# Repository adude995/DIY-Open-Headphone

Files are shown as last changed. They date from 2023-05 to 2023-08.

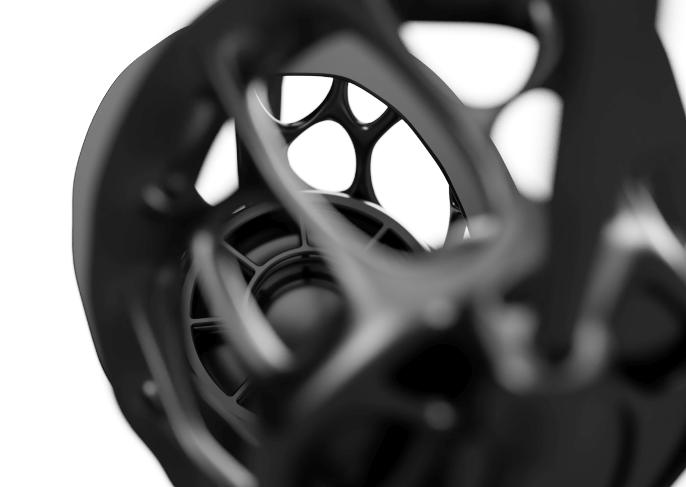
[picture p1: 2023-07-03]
photos/rendering_2.png

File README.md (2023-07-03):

# mushroom - DIY ultralight open headphones

## Overview

This project is about acoustically transparent DIY 3D-printable headphones. They are designed to be used in combination with signal processing, either with binaural convolution or just a simple eq.

The design is kept simple and only requires 5 (+2) printed parts in total. Their acoustically transparent design makes them not only nice open back headphones but also perfectly suited for AR applications. If bass reproduction is more important than transparency, felt pads, acting like additional masses, can be put in front of the driver.

This repository relates to the open-acces paper "Ultralight circumaural open headphone", which was presented at the Audio Engineering Society Convention in May 2023 in Espoo, Finland. Therein, development process and measurements are documented. It can be found at https://www.aes.org/e-lib/browse.cfm?elib=22075

Plans and instructions to build them on your own are found below or will be added soon.

## Background

The main question considered in this project was how a headphone design could look like, if the benefits of equalization were considered in the development process from the start. In addition, since the work was intended to be a freely accessible DIY project, 3D printing was chosen as the manufacturing method to ensure feasibility and repairability.

## Features

- 3D printable design
- Optimized for mixed and virtual reality
- Great for listening to music
- Convertable to different needs (hear-through vs low-end)

## Getting Started

To get started with building these headphones, follow these steps:

1. Clone or download this repository to your local machine.
2. Open the design files in your preferred 3D printing software.
3. Print the design using the recommended settings (to come, if not yet available)
4. Follow the assembly instructions provided in the repository to build the headphones together. (to come, if not yet available)

## License

This project is licensed under the Creative Commons Attribution-NonCommercial-NoDerivatives 4.0 International License. See the LICENSE file for more information.

## Contact

If you have any questions or feedback about this project, please contact me at alex.muelleder@gmx.at.

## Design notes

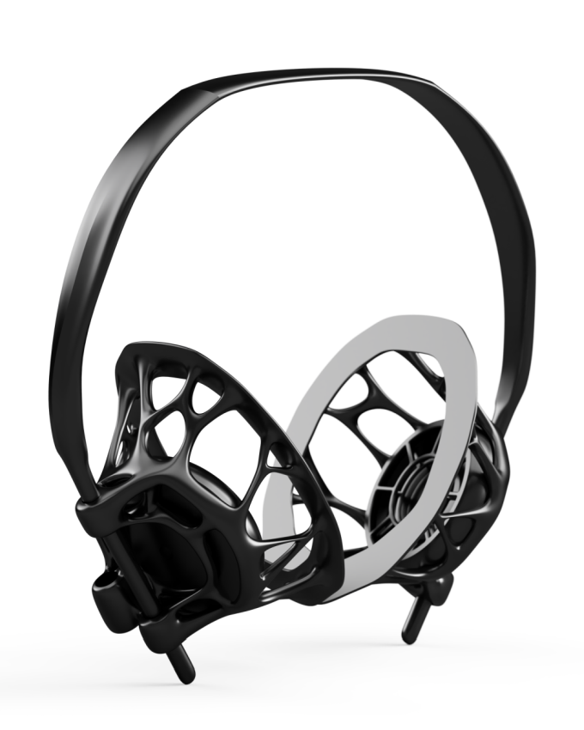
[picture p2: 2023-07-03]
photos/rendering_1.png

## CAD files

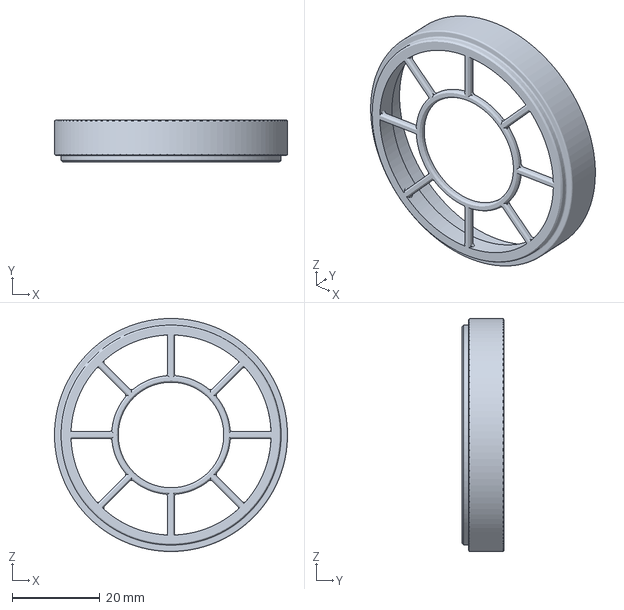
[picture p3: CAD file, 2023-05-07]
files/driver_insert_v0.1.3mf
53.0 x 9.50 x 53.0 mm

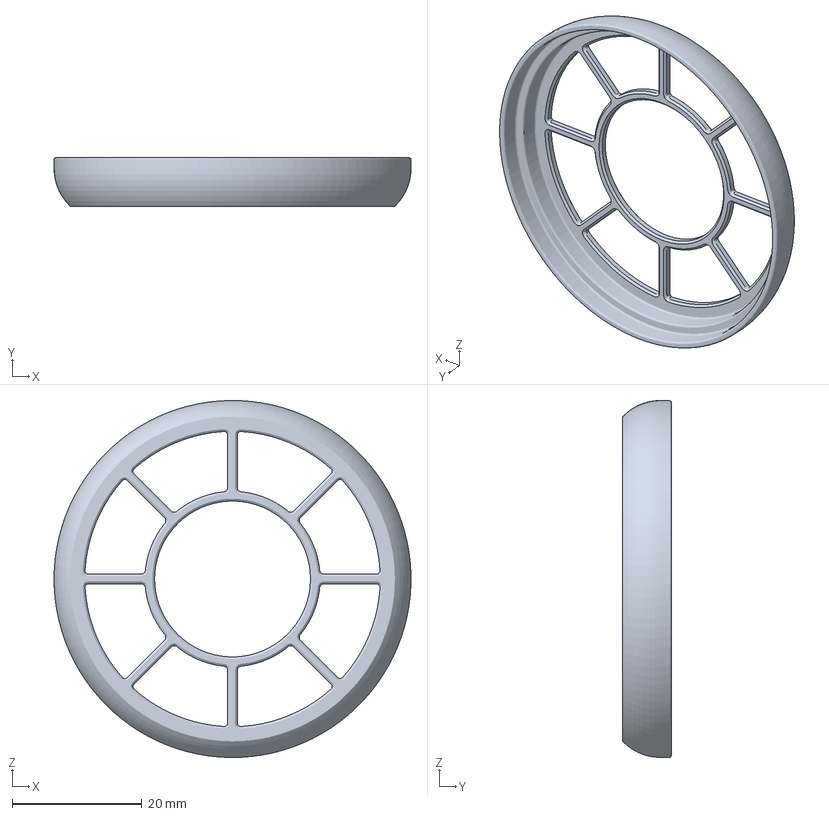
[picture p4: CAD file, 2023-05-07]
files/padholder_v0.1.3mf
55.0 x 7.50 x 55.0 mm

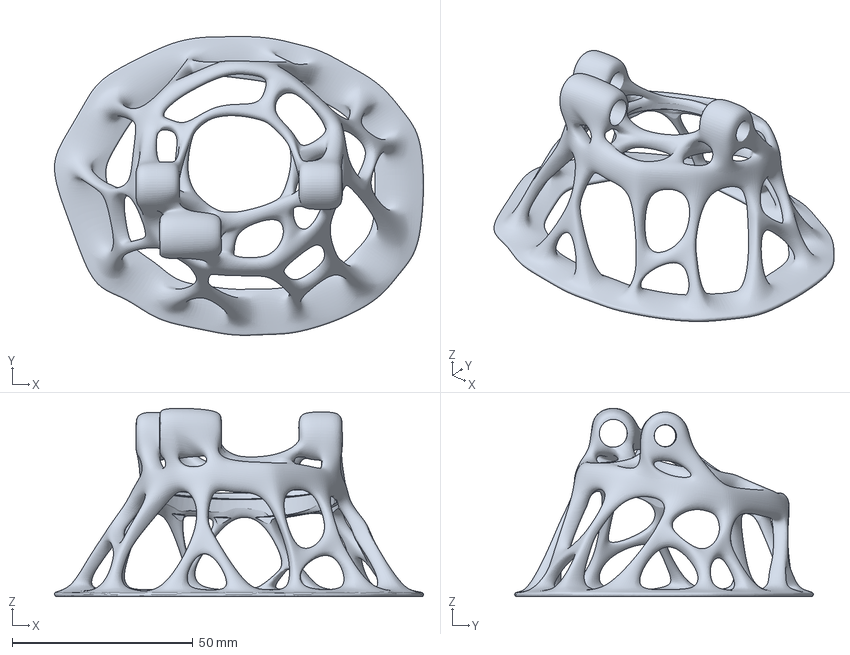
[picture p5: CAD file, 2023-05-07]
files/earcup_left_v0.1.3mf
102.0 x 82.6 x 52.1 mm

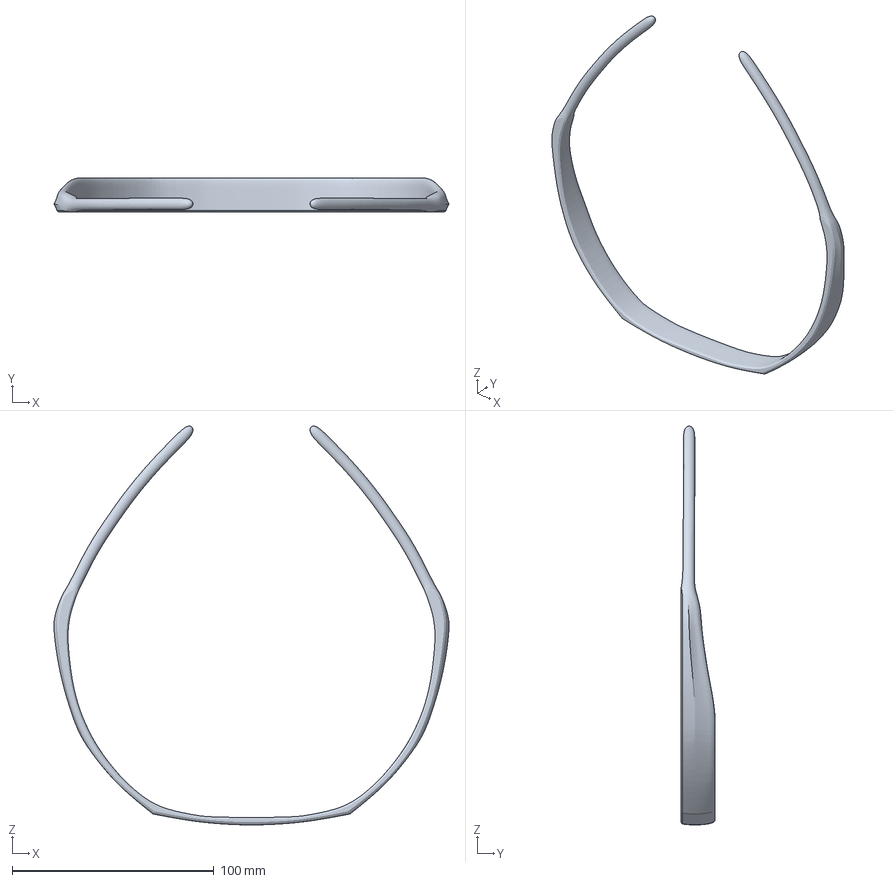
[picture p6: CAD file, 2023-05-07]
files/headband_v0.1.3mf
195.9 x 17.1 x 197.8 mm

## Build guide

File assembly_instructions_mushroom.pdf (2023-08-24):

# Assembly Instructions DIY headphone MushRoom

Alexander M¨ulleder

August 24, 2023

## Material List

- 2x Peerless HPD-50N25PR00-32
- 2x Rean NYS 240 BG
- 1x Headphone cable (1x 3.5 mm stereo to 2x 3.5 mm mono)
- approx. 150g of PCTG or PETG
- 3 mm spacer fabric of the size 15 cm x 20 cm
- 3 mm felt of the size 10 cm x 10 cm

## Necessary tools

- Soldering iron
- Nose pliers or similar
- cutter
- Scissors

## 1 Download files

If you haven’t already downloaded all files, do so at: https://github.com/adude995/DIY-Open-Headphone

1

## 2 3D-Printing

Printing settings are the same for all parts, except for the scaling factor of the earcup part which is 1.05 and should be applied manually in the slicer of choice. Since the parts are hold together by friction, the fit should be tight, but not too tight. Depending on the printer, without scaling, the inserted driver expanding the driver insert could make it hard to put the piece into place afterwards as seen in 3.3.

Print Settings:
”Glass”-settings for strength (and look if used with transparent filament) but slow

## 3 Assembly

Make sure all the support material as well as any strings left from 3D printing are removed precisely from the prints. Stringing in the driver insert, for example, can result in rattling afterwards.

### 3.1 Driver housing

Carefully push the drivers into of the driver housing parts.
Make sure air is not encased between the driver and some flat surface. This will dent the membrane and could damage it.

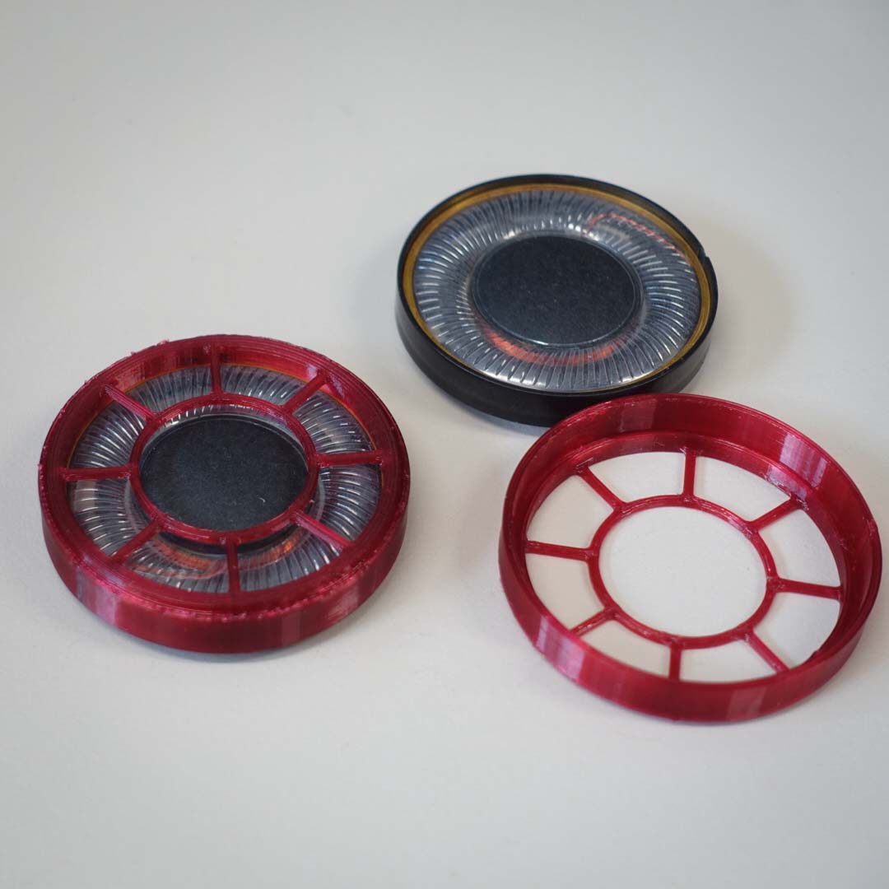
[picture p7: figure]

Figure 1: Peerless HPD-50 driver inserted into 3D-printed housing part.

Then take the inner brass part of the REAN connector and screw it into the designated hole in the ear cup. Use nose pliers and try not to slipp off too often since the brass parts can wear off fast.

2

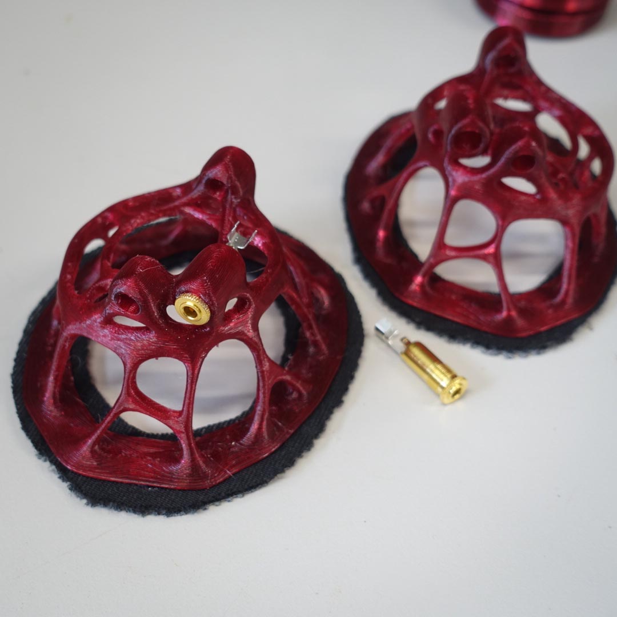
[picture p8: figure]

Figure 2: Earcups with REAN NYS 240 screwed directly into the 3D print.

### 3.2 Wiring

Start by soldering the wires to the driver.
To avoid any force to the driver, caused by cables not fitting the ear cup later on, hold the driver in place first, to the idea of how the wires need to be orientated.

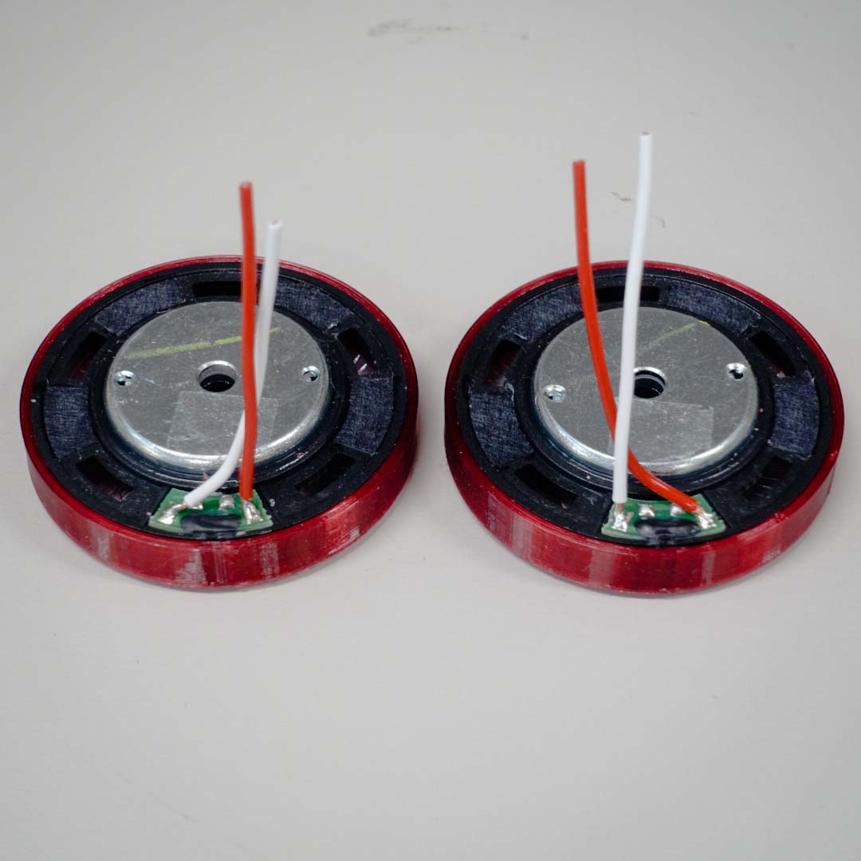
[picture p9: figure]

Figure 3: Cables soldered to the driver in a way it fits in the earcup.

Push the driver housing with the inserted driver into the earcup. Watch out that there is no force from the cables to the driver.

Cut the cable to the appropriate length and solder them to the connector with the pin allocation in mind.

3

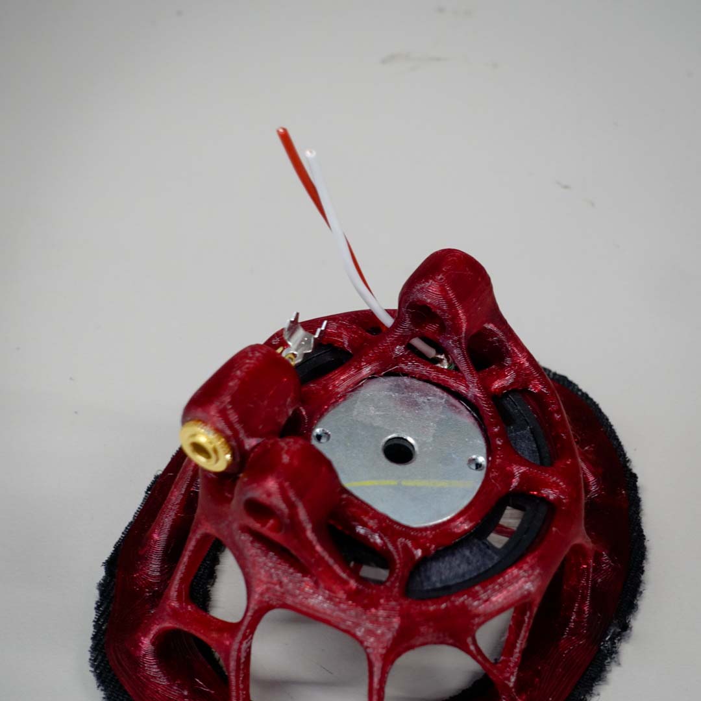
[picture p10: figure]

Figure 4: Driver placed in the earcup.

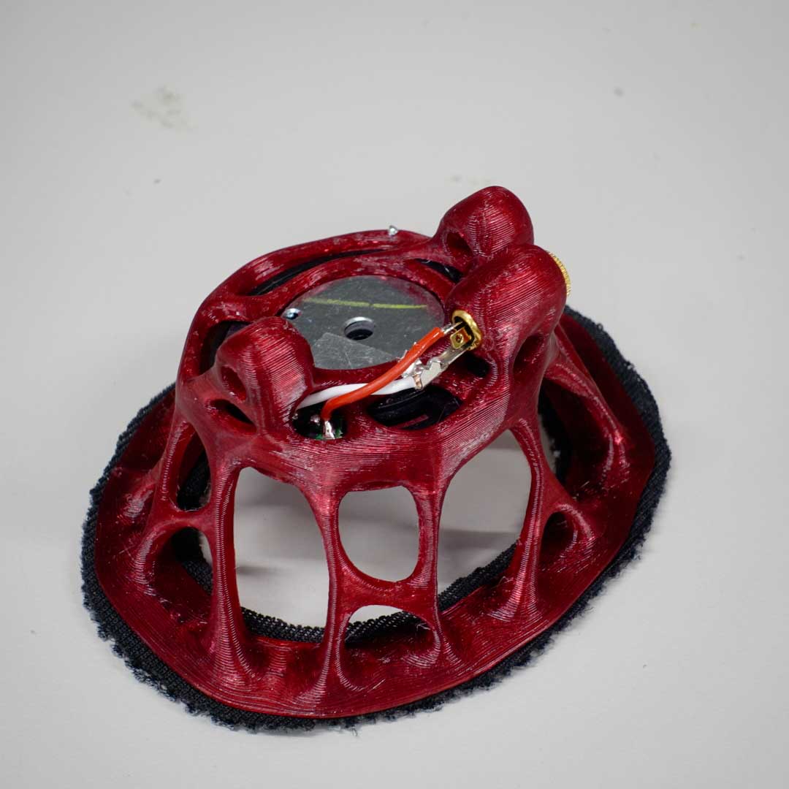
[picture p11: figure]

Figure 5: Earcup with soldered driver

### 3.3 Spacer Fabric and Felt

Cut Fabric and glue into place.

4

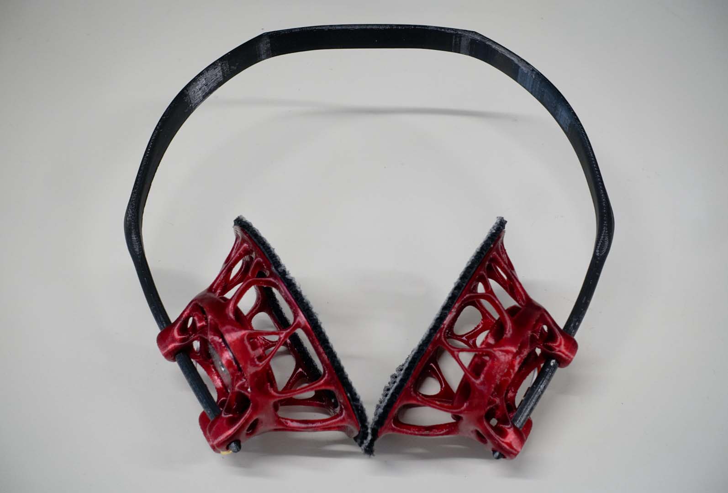
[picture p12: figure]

Figure 6: Finished headphone

## A Printing parameters

Printer Settings
Layer height | 0.2 mm
Perimeters | ∞
Solid layers | n.a
Seam position | Aligned
Perimeter generator | Arachne
Infill | n.a
Speed perimeter | 20mm/s
Speed small perimeter | ?
Speed external perimeter | ?
Filament Settings
Extrusion multipl. | 1.05
Nozzle temperature | 250 ◦
- 255 ◦
Bed temperature | 90 ◦
- 100 ◦
Fan speed | 25 %
Retraction length | 0 mm

5

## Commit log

2023-05-02 Create 4x Einsatz und Unten (just here for testing).3mf
    first commit
2023-05-07 all files added
    [driver_insert_v0.1.3mf, earcup_left_v0.1.3mf, headband_v0.1.3mf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]
